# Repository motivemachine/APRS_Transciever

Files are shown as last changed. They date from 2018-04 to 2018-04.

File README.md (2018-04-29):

# APRS_Transciever
An in development design for a complete, standalone transciever for voice and aprs digital communication for the 2meter/70cm band. It is primarily based on the DRA818 radio module and controlled with an arduino. 

This project is made possible for amateur designers like me thanks to the work of:

markqvist and his APRS library:
https://github.com/markqvist/LibAPRS

darksidelemm and his DRA818 serial library:
https://github.com/darksidelemm/dra818

Progress:
Currently the basic Kicad schematic is complete, using an arduino nano and two bss183 mosfets to convert the 5v IO to 3.3v for the dRA818V. Resistors on Arduino Nano pins 4-7 form the DDS as used with LibAPRS. No other interfaces are yet included, but many are planned (gps, display, etc.)

Next steps:
After further breadboard testing, complete designs for the PCBs in Kicad. The first design will be for a single-sided PCB for etching at home and further development. A two layer production design will follow after any changes are made

Begin adding some other interfaces to the circuit, such as GPS, sh1106 OLED display, battery management circuits,and other useful telemetry

Firmware will mostly be based on the arduino libraries of others, but will be uploaded here as changes are made.

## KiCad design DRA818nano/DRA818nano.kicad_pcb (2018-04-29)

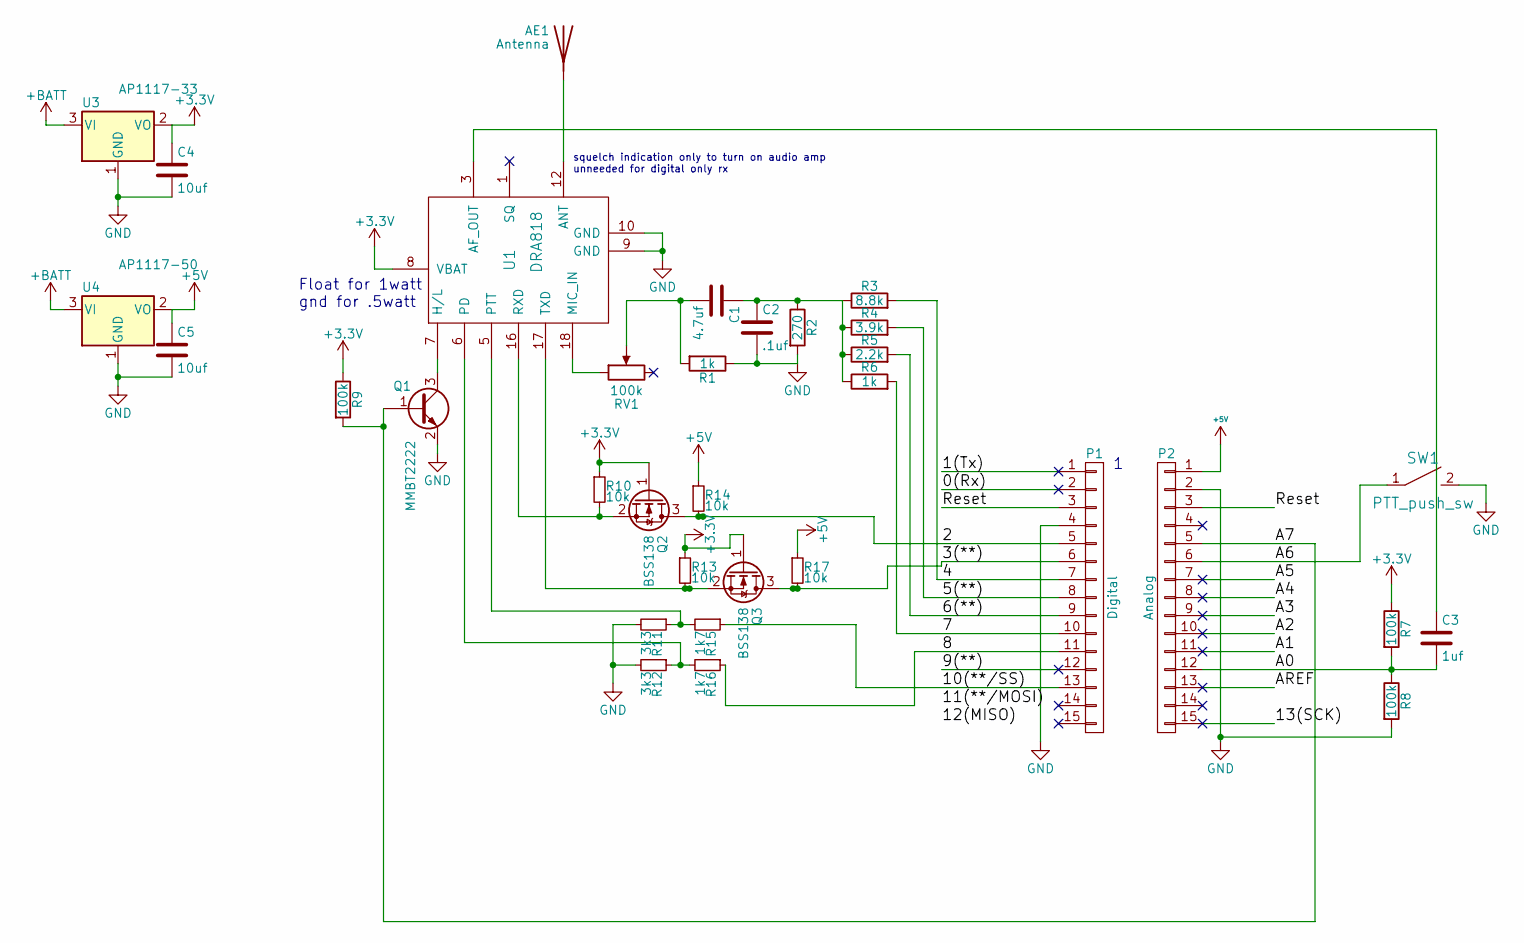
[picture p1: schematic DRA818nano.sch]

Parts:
AE1: Antenna; Pin_Header_Straight_1x01_Pitch2.54mm
C1: 4.7uf; C_0805
C2: .1uf; C_0805
C3: 1uf; C_0805
C4, C5: 10uf; C_0805
P1: Digital; Socket_Strip_Arduino_1x15
P2: Analog; Socket_Strip_Arduino_1x15
Q1: MMBT2222; SOT-23
Q2, Q3: BSS138; SOT-23
R1, R6: 1k; R_0805
R2: 270; R_0805
R3: 8.8k; R_0805
R4: 3.9k; R_0805
R5: 2.2k; R_0805
R7, R8, R9: 100k; R_0805
R10, R13, R14, R17: 10k; R_0805
R11, R12: 3k3; R_0805
R15, R16: 1k7; R_0805
RV1: 100k; Potentiometer_Trimmer_ACP_CA6v_Horizontal
SW1: PTT_push_sw; SW_PUSH_6mm_h7.3mm
U1: DRA818
U3: AP1117-33; SOT-223-3_TabPin2
U4: AP1117-50; SOT-223-3_TabPin2

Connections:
+3V3: C4.1, Q2.1 (G), Q3.1 (G), R7.1, R9.1, R10.1, R13.1, U1.8 (VBAT), U3.2 (VO)
+5V: C5.1, P2.1, R14.1, R17.1, U4.2 (VO)
+BATT: U3.3 (VI), U4.3 (VI)
/0(Rx): P1.2
/1(Tx): P1.1
/2: P1.5, Q2.3 (D), R14.2
/3(**): P1.6, Q3.3 (D), R17.2
/4: P1.7, R3.2
/5(**): P1.8, R4.2
/6(**): P1.9, R5.2
/7: P1.10, R6.2
/8: P1.11, R16.1
/9(**): P1.12
/10(**/SS): P1.13, R15.1
/13(SCK): P2.15
/A0: C3.2, P2.12, R7.2, R8.1
/A1: P2.11
/A2: P2.10
/A3: P2.9
/A4: P2.8
/A5: P2.7
/A6: P2.6, SW1.1
/A7: P2.5, Q1.1 (B), R9.2
/AREF: P2.13
/Reset: P1.3, P2.3
GND: C2.2, C4.2, C5.2, P1.4, P2.2, Q1.2 (E), R1.1, R2.2, R8.2, R11.2, R12.2, SW1.2, U1.9 (GND), U1.10 (GND), U3.1 (GND), U4.1 (GND)
unnamed: AE1.1, U1.12 (ANT)
unnamed: C1.1, C2.1, R2.1, R3.1, R4.1, R5.1, R6.1
unnamed: C1.2, R1.2, RV1.2
unnamed: C3.1, U1.3 (AF_OUT)
unnamed: Q1.3 (C), U1.7 (H/L)
unnamed: Q2.2 (S), R10.2, U1.16 (RXD)
unnamed: Q3.2 (S), R13.2, U1.17 (TXD)
unnamed: R11.1, R15.2, U1.5 (PTT)
unnamed: R12.1, R16.2, U1.6 (PD)
unnamed: RV1.1, U1.18 (MIC_IN)

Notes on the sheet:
Float for 1watt gnd for .5watt
squelch indication only to turn on audio amp unneeded for digital only rx

Board: 2 copper layers, 37 parts (0 on the bottom side), 26 nets, no tracks yet.

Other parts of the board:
P3, P4, P5, P6: CONN_01X01; 1pin_Nano
